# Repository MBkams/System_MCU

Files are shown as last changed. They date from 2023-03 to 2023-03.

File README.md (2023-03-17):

# System_MCU

## Travaux pratiques : Systèmes à microcontroleurs

### 1.2 Le microcontrôleur sous KiCAD

13) Pourquoi PB9 est relié à la maase?
14) Quel est le rôle de L1, C5 et C7 ? :
    Le rôle des composants L1, C5 et C7 est de filtrer la tension d'alimentation venant du 3,3V. L'association de ces composants forme un filtre passe-bas du second ordre.

### 3. Le reste du schéma

3) Quelle page de la datasheet indique les valeurs des condensateurs ? :
   La page 1 : elle indique que la capacité doit être au moins de 0,47uF.
   La page 3 : elle indique que la capacité à une valeur typique de 1uF.
4) Quelle page de la datasheet nous indique les valeurs de condensateurs ? :
   la valeur de condensateurs des  du DAC est donnée en page 25 de la datasheet.

6) Quel est le rôle de la broche CS ?
La broche CS correspond au « Chip Enable » . Un état bas sur cette broche permet d’activer la clock et les données.

7) Quel est le rôle de la broche LDAC ?
La croche LDAC est utilisée pour transférer le registre de verrouillage d'entrée vers le registre du DAC. Lorsque cette broche est à létat bas, la sortie VOUT est mis à jour avec le contenu du registre d'entrée. 

8) Pourquoi le signal MISO n’est pas utilisé ?
Le signal MISO a été connecté directement au STM32, comme décrit dans la procédure. Le signal MOSI transmets les données du maître, le STM32, jusqu’à l’esclave et inversement pour le signal MISO (de l’esclave au maître). Comme on souhaite seulement communiquer du maître jusqu’à l’esclave, on a pas besoin d’utiliser le signal MISO.

10) Où trouve-t-on les indications du pinout du connecteur SWD ?
On trouve ces indications dans le manuel d’utilisation.

### 4. Affectation des empreintes

3) Que signifie 0805 ? 0603 ? 1206 ?
Ces informations corresponent aux dimensions des composants. Exemple avec 0805 : le composent mesure 0.08 pouces sur 0.05 pouces. (a noter que 0.1 pouce égal 2,54 mm)

4) Que signifie LQFP ? SOT-223 ? SOIC ?
QFP décrit le package du composent, cela signifie : Quad Flat Package, qui est un circuit intégré monté en surface. Et LQFP signifie : Low-profile Quad Flat Package, voulant dire que le package est plus petit que le PCB.

SOT : Small-Outline Transistor.
C'est une famille de transistor discrets pour des montages en surface.

SOIC : Small Outline Integrated Circuit 
Boîtier de circuit intégré monté en surface qui occupe une surface inférieure d’environ 30 à 50% à celle d’un boîtier double en ligne (DIP) équivalent, avec une épaisseur typique inférieure de 70%. Ils sont généralement disponibles dans les mêmes brochages que leurs homologues DIP IC. La convention pour nommer le package est SOIC ou SO suivi du nombre de broches. Par exemple, un 4011 à 14 broches serait logé dans un boîtier SOIC-14 ou SO-14. (oui ça vient de Wikipédia, mais on a lu !)

### 3.1 Activation des LL drivers

##### 2. Lors de la génération de code avec la bibliothèque LL, on remarque les changements de synthaxe des appels de fonctions.

##### 4. __STATIC_INLINE permet de définir une fonction en ligne et de la rendre statique.

##### 5. La fonction est définit aussi dans un .h . Néamoins, __STATIC_INLINE permet une optimisation au niveau compilateur lors de l'appel de fonction.

### 3.2 LED simple

##### 2. Pour une configuration du timer de la LED à une fréquence 1kHz et une résolution de 8bits, il faut déterminer les valeurs de PSC et ARR comme suivant :

- Période = (PSC + 1) * (ARR + 1) / Fréquence du clock du timer
- L'horloge du timer est à 32 Mhz. Donc PSC = 125 et ARR = 255.

### 3.3 LED avec timer

##### 3. Les valeurs de PSC et ARR sont 125 et 255 respectivement.

##### 6. La routine d'interruption se situe au nivau TIM21_IRQHandler(void).

##### 7. Avec l'utilisation de la bibliothèque LL, il doit manquer la remise à zero du flag.

##### 8. Cela peut entraîner la routine d'interuption en boucle.

##### 9. Il faut faire une remise à zero du flag.

### 3.4 UART, un simple echo

##### 5. J'ai modifié la défintion des fonctions SerialTransmit et SerialReceiveChar afin de les adapter avec HAL :)

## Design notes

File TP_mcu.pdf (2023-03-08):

# TP Systèmes à microcontrôleurs

L’objectif de ce TP en 4 séances est de concevoir, assembler et tester une carte électronique contenant un microcontrôleur STM32. Le TP a été conçu avec la version 6.0.9 de KiCAD, mais devrait être réalisable avec d’autres versions.

Cette carte sera constituée des composants suivants :
— Microcontrôleur STM32L021K4T6,
— DAC MCP4801-E/SN,
— Régulateur linéaire BU33SD5WG-TR,
— 2 LED au format 0603,
— Connecteur de programmation FTSH-107-01-F-DV,
— Plusieurs composants passifs (résistances, condensateurs...) en 0805.

La carte est donc munie d’un ADC (intégré au MCU) et d’un DAC (composant externe sur la carte). Pour démontrer le bon fonctionnement de la carte, vous programmerez un filtre numérique simple.
L’ordre des séances est le suivant :
1. Schéma, association empreintes
2. Routage du circuit
3. Soudure, test...
4. Écriture du firmware

## 0 Utilisation de git

Les outils de gestion de version permettent de travailler facilement à plusieurs sur du code, ou autre. L’outil git est probablement le plus courant. C’est celui que nous allons utiliser.
Sous Linux, l’outil s’utilise simplement en ligne de commande. Sous Windows, il existe des outils. Je suis un Linuxien, débrouillez-vous.
Git est un outil puissant, complet et complexe, mais nous n’aurons besoin de connaître que 5 commandes :
— git clone : Cloner un projet, c’est la première étape pour récupérer son projet, ou n’importe quel projet publique.
— git pull : Récupérer les dernières modifications
— git add <fichier> : Enregistrer des fichiers auprès de git
— git commit -m "Message" : Réaliser un commit, c’est à dire enregistrer les modifications locales. On peut l’utiliser comme un verbe. Ex : "Oups, j’ai oublié de commiter mon code".
— git push : Pousser du code sur le serveur. Le commit se faisant localement, cette commande permet de pousser le commit sur le serveur.

Je vous recommande fortement d’utiliser cet outil pour tout vos TP, que ce soit pour le code ou pour les compte-rendu.

ENSEA | Page 1/23 | TP Linux Embarqué

1. Si ce n’est pas déjà fait, créez un compte (par étudiant) sur le site suivant : https://github.com/
2. Créez un nouveau repository. Laissez-le en public. Vous pouvez ajouter une description et un fichier README.
3. Récupérez l’adresse du projet. Cliquez sur Code, choisissez SSH, puis copiez l’adresse.

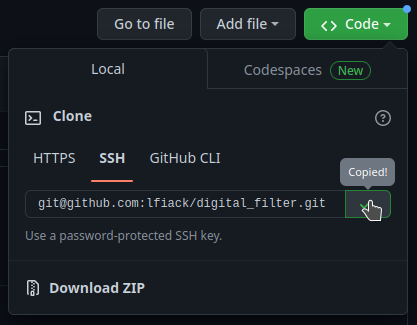
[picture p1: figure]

4. Clonez le projet. Dans un terminal, tapez la commande suivante :
git clone <adresse_du_depot>.
5. Modifiez le fichier README.
6. Réalisez votre premier commit. Tapez les deux commandes suivantes : git add .
git commit -m "First!"
7. Poussez les modifications sur le repository distant :
git push
8. Vérifiez que les modifications ont bien été prises en compte sur https://github.com/

Quelques bonnes pratiques :
— Faire un git pull au début de chaque session de travail (on sait jamais, peut-être que mon binôme a travaillé ?)
— Commiter régulièrement :
— Dès que quelque chose fonctionne
— À la fin de la session de travail
— Éviter de commiter du code qui plante (à l’école, ça peut entrer en contradiction avec le point précédent...)
— Mettez un message utile !
— Utiliser le fichier README comme document de travail.
ENSEA | Page 2/23 | TP Linux Embarqué

## 1 Saisie du schéma

### 1.1 Création de la structure du projet

Le projet contiendra du hardware et du software. Il est impératif de bien structurer le dossier de travail.
1. Dans le dossier git, créez un dossier hardware, un dossier firmware et un dossier datasheets.
2. Téléchargez les datasheets de tous les composants, et copiez les dans le dossier datasheets. Attention, la documentation du STM32 est en plusieurs parties. Téléchargez également la datasheet de la sonde de programmation STLINK-V3MINI. Pensez à commiter.
3. Lancez STM32CubeMX. C’est un outil pratique lors de la conception d’une carte, notamment pour gérer le pinout.
4. Créez un projet pour le STM32L021K4.
5. Dans SYS, activez Debug Serial Wire.
6. Activez l’USART2 en mode Asynchrone. Gardez les paramètres par défaut, et notez le baud rate.
7. Dans l’onglet Clock Configuration, configurez l’horloge système à sa valeur maximale.
8. Dans Project Manager > Code Generator, cochez Generate peripheral initialization as a pair of ’.c/.h’ files per peripheral
9. Sauvegardez dans le dossier firmware. L’initialisation n’est pas terminée, vous y reviendrez en temps voulu.
10. Pensez à commiter.

### 1.2 Le microcontrôleur sous KiCAD

1. Lancez KiCAD. Créez un projet dans le dossier hardware.
2. Cliquez sur Place > Add symbol (Vous pouvez commencer à apprendre les raccourcis.)
3. Chechez et placez le composant STM32L021K4Tx.
4. Cliquez sur Place > Add Power (Aussi présent dans le menu à droite.)
5. Placer GND proche des pins VSS du STM32, et câblez-les comme dans la capture ci-dessous.

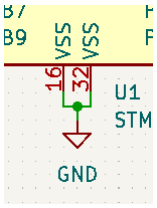
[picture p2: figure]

ENSEA | Page 3/23 | TP Linux Embarqué

6. Ajouter deux autres symboles +3.3V et +3.3VA selon la capture ci-dessous.

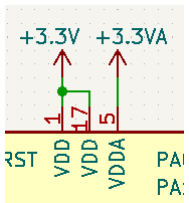
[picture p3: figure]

7. Cliquez sur Place > Add Label Placez le label sur l’entrée NRST et nommez le NRST.

Il sera plus tard relié au port de programmation. Deux signaux connectés à un même label sont reliés électriquement. Ça permet de simplifier la lecture du schéma.
8. Ajoutez les labels correspondant aux signaux définis dans STM32CubeMX (USART2_RX, USART2_TX, SWDIO, SWDCLK).

D’ailleurs, c’est peut-être le bon moment de finaliser le pinout
9. Activez l’entrée IN1 de l’ADC. Ce sera l’entrée analogique pour le filtre.
10. Dans TIM2, mettez Clock Source à Internal Clock et Channel 1 à PWM Generation CH1. On s’en servira pour faire varier la luminosité de la LED.
11. Enfin, configurez les signaux nécessaires pour l’utilisation du DAC. Le résultat final pourrait ressembler à ça :

Sauvegardez.

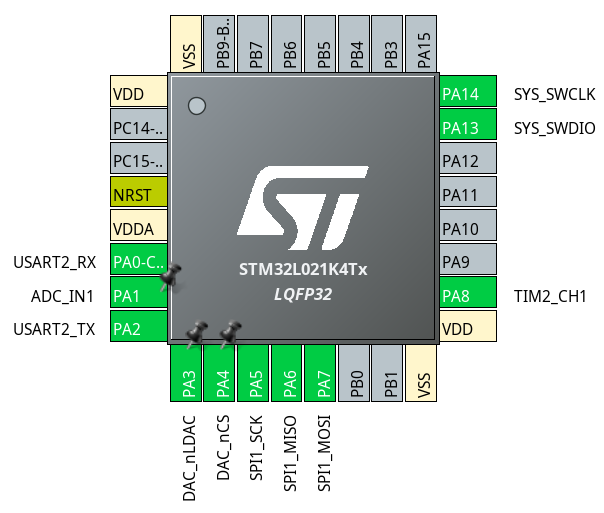
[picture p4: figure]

ENSEA | Page 4/23 | TP Linux Embarqué

12. Il est temps d’ajouter le reste des composants. Ajoutez les composants suivants :
— 6x C_Small
— 1x L_Small
— 2x R_Small
— 1x LED_Small

Le schéma correspondant à la partie microprocesseur pourrait ressembler à ça :

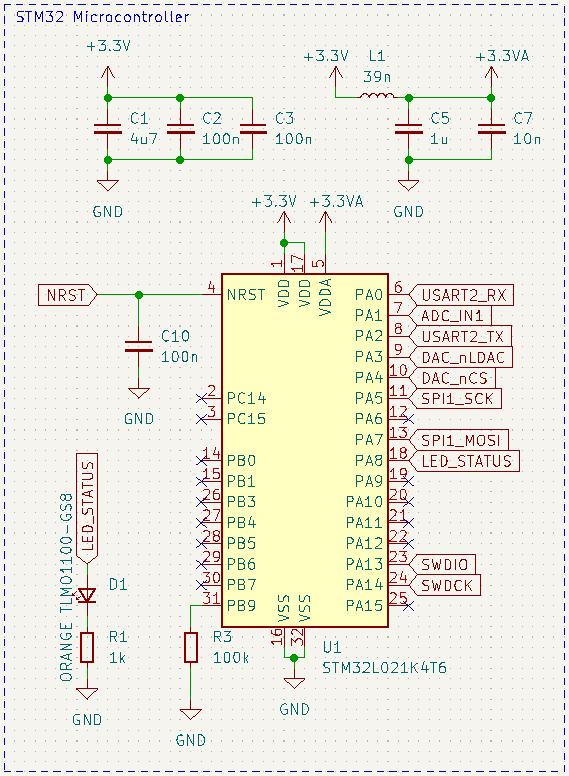
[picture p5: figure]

Notez qu’il n’est pas nécessaire d’annoter les composants à ce stade. Ce sera fait automatiquement plus tard. Les composants peuvent donc être nommés C ?, L ?, U ?...
Par contre, il est important de bien noter les valeurs des composants (4u7, 39n, 1k...)
13. Pourquoi PB9 est relié à la masse ? (Répondez à cette question, et aux suivantes, dans le README du repo git.)
14. Quel est le rôle de L1, C5 et C7 ?
ENSEA | Page 5/23 | TP Linux Embarqué

### 1.3 Le reste du schéma

Pour générer la tension de 3.3V à partir du 5V, nous utiliserons le régulateur linéaire LDO BU33SD5WG-TR. Il n’est pas présent dans la librairie de KiCAD. Pour éviter d’avoir à dessiner un nouveau symbole, nous pouvons simplement utiliser un autre composant qui dispose du même boitier, comme le MCP1802x-xx02xOT.
1. Ajouter le composant MCP1802x-xx02xOT et renommez-le en BU33SD5WG-TR
2. Câblez le régulateur de tension en vous basant sur la figure suivante :

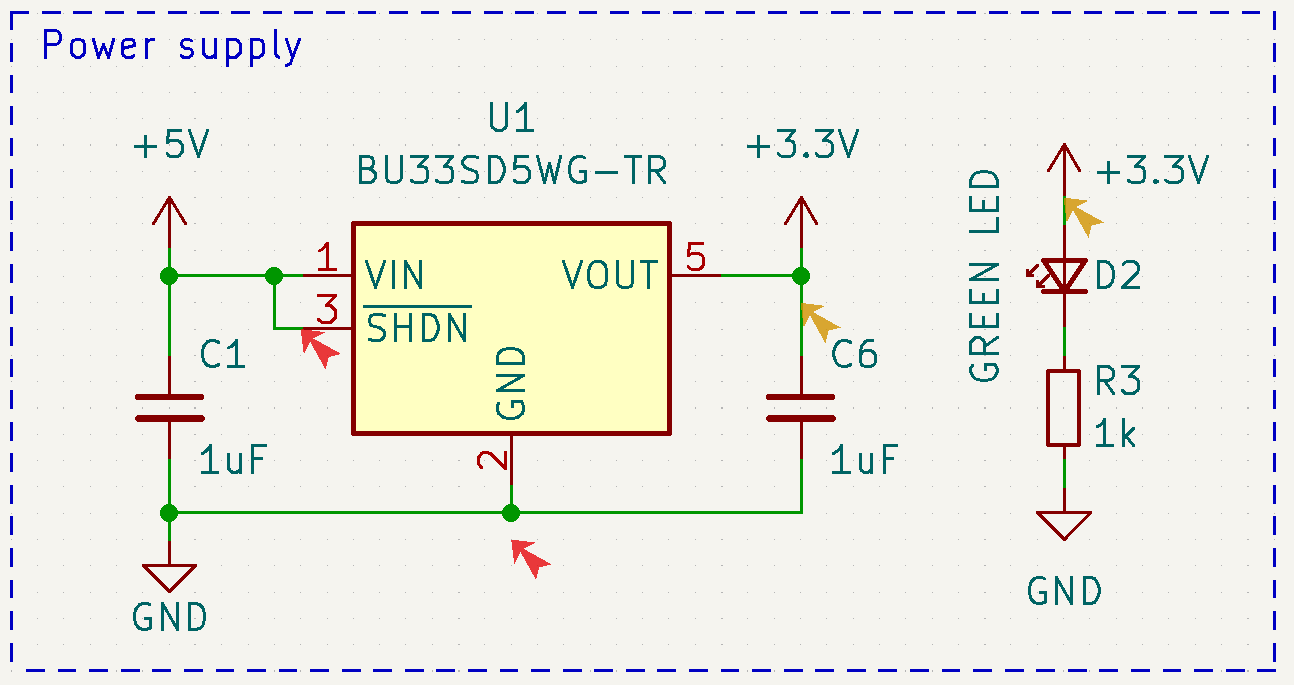
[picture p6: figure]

3. Quelle page de la datasheet indique les valeurs des condensateurs ?
4. Tracez le schéma du DAC en vous inspirant de la figure suivante :

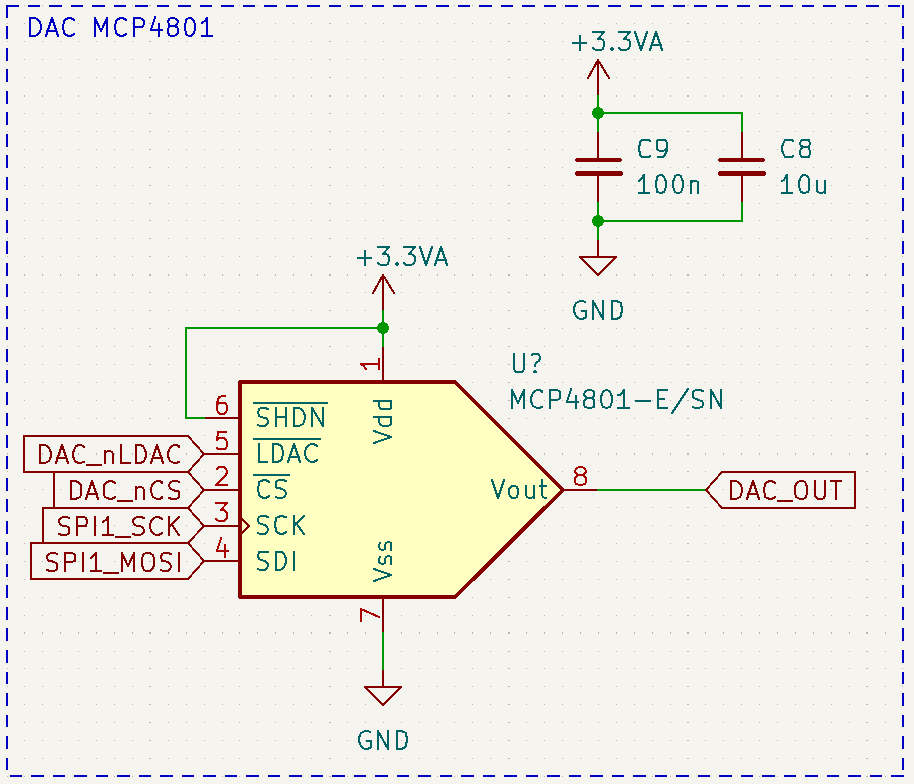
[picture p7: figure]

5. Quelle page de la datasheet nous indique les valeurs de condensateurs ?
6. Quel est le rôle de la broche CS?
7. Quel est le rôle de la broche LDAC ?
8. Pourquoi le signal MISO n’est pas utilisé ?
ENSEA | Page 6/23 | TP Linux Embarqué

9. Câblez les connecteurs comme dans la figure suivante :

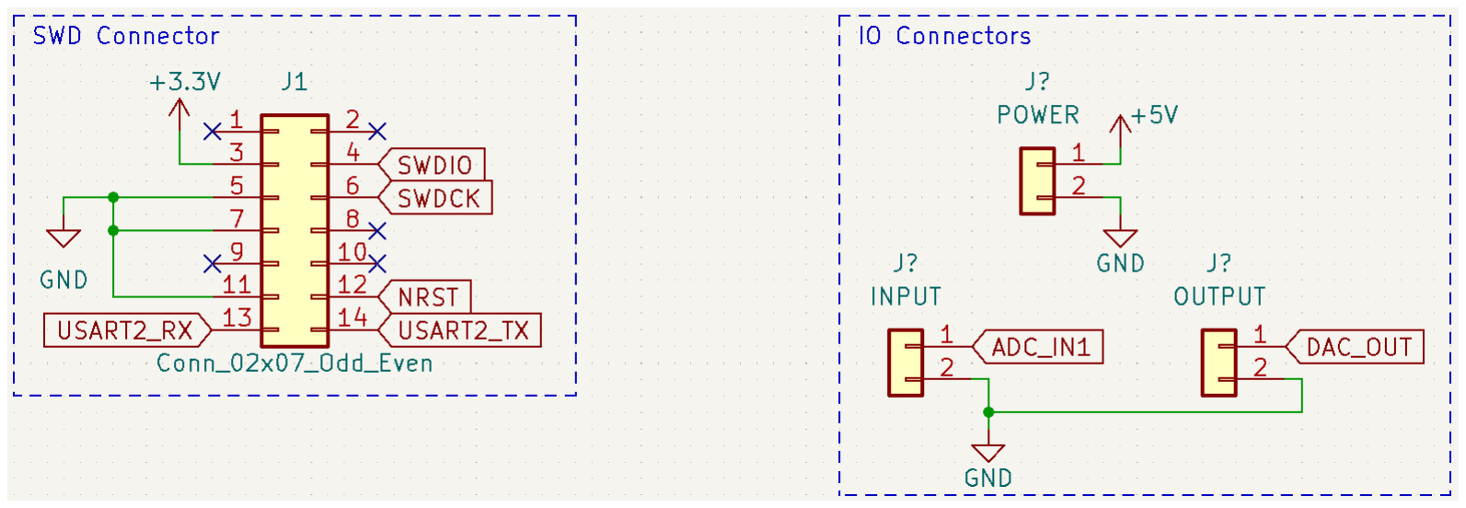
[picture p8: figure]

10. Où trouve-t-on les indications du pinout du connecteur SWD ?
11. Numérotez les composants en cliquant sur Tools > Annotate Schematic...
12. Vérifiez les ERC (Electrical Rule Check) en cliquant sur Inspect > Electrical Rules Checker.
Les erreurs suivantes peuvent être ignorées. S’il y en a plus, c’est qu’il y a peut-être des erreurs dans le schéma, corrigez les.

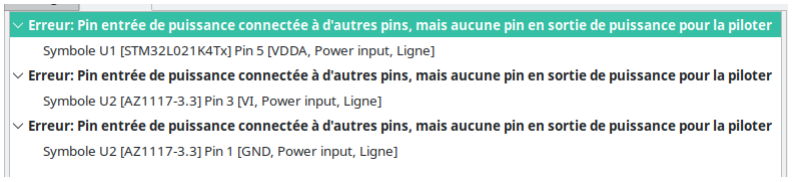
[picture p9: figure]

ENSEA | Page 7/23 | TP Linux Embarqué

### 1.4 Affectation des empreintes

Vous avez fini le tracé du schéma. Il faut maintenant, pour chaque composant, associer un empreinte.
1. Cliquez sur Tools > Assign Footprints...
2. Faire les associations selon la figure suivante. Attention, en fonction du placement des composants dans le schéma, les composants n’ont peut-être pas les mêmes noms.

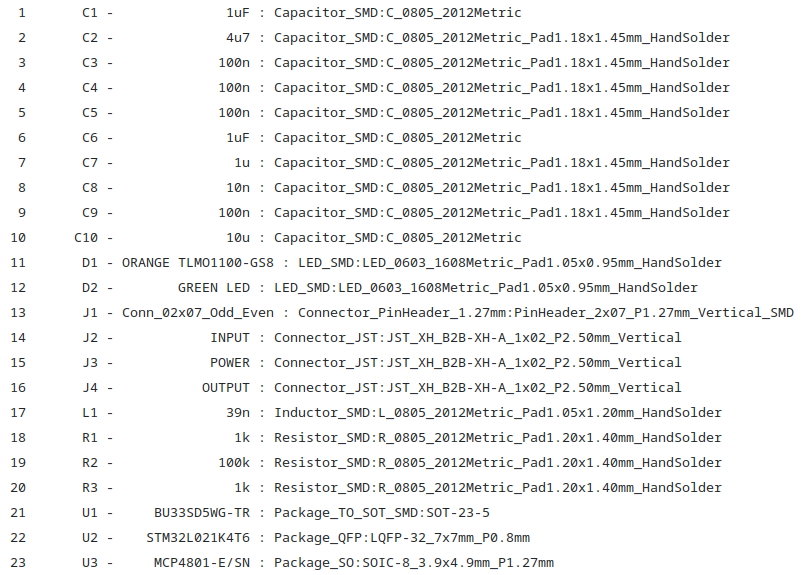
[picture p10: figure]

Pour trouver plus facilement les empreintes, il peut être utile de bien confi-

gurer les filtres
3. Que signifie 0805 ? 0603 ? 1206 ?
4. Que signifie LQFP ? SOT-223 ? SOIC ? Ne vous contentez pas de donner le sigle, j’attends une petite description (vous pouvez copier-coller depuis wikipedia, mais lisez avant quand même))

Félicitations ! Vous avez tracé le schéma complet de votre circuit et avez associé une empreinte à chaque symbole dans le schéma. Dans l’étape suivante, ces informations seront importées dans le logiciel de routage.
Faites vérifier le schéma à l’enseignant avant de passer à la suite.
ENSEA | Page 8/23 | TP Linux Embarqué

## 2 Routage du circuit

### 2.1 Placement des composants

1. Ouvrez l’Éditeur de PCB.
2. Cliquez sur Tools > Update PCB from Schematic...
Les composants sont mis en vrac, les connexions à router sont représentées par des traits fins. Cet ensemble de traits est appelé chevelu (ou ratsnest en Anglais).

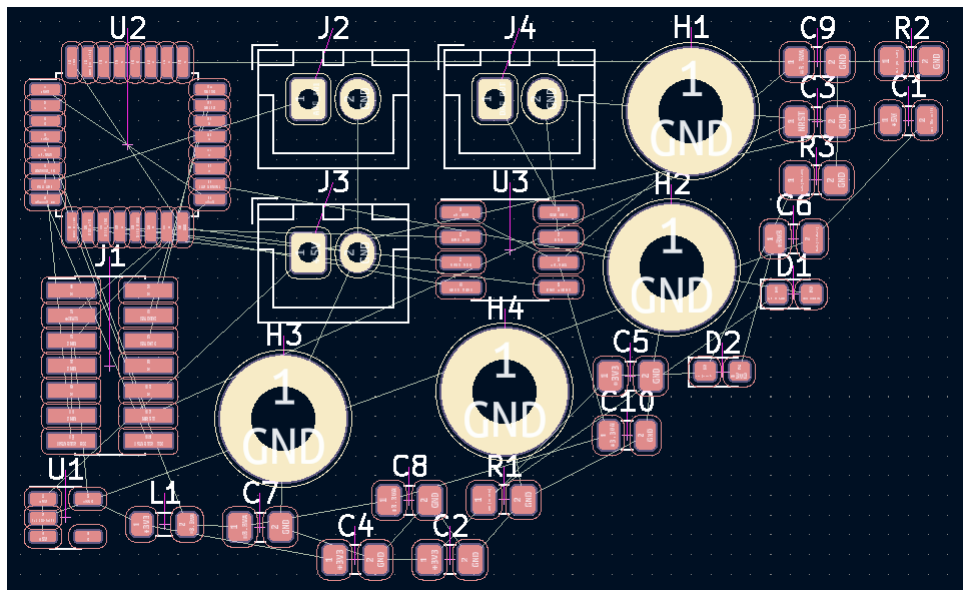
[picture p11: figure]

Dans la figure ci-dessus, il y a 4 grandes pastilles que vous n’avez pas chez vous. Elles serviront de trous de fixation. Il y a plusieurs méthodes pour les ajouter. Vous allez les rajouter dans le schéma.
3. Dans l’Éditeur de Schématique, ajouter les composants suivants :

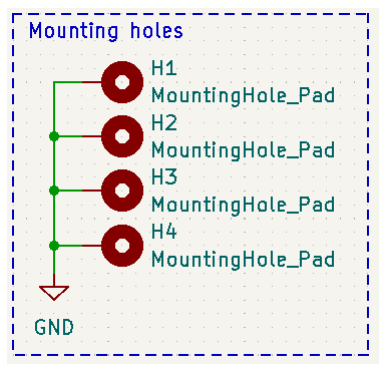
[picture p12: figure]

4. N’oubliez pas de faire le lien avec les empreintes :
5. Réglez la grille à 1mm.
ENSEA | Page 9/23 | TP Linux Embarqué

6. Commencez par placer les trous de fixation à 50mm de distance sur l’axe X et à 40mm de distance sur l’axe Y.
7. Tracez les contours du circuit. Cliquez sur Edge.Cuts dans le panneau de droite. Utilisez les lignes droites et les arcs de cercle pour obtenir quelque chose comme dans la figure suivante :

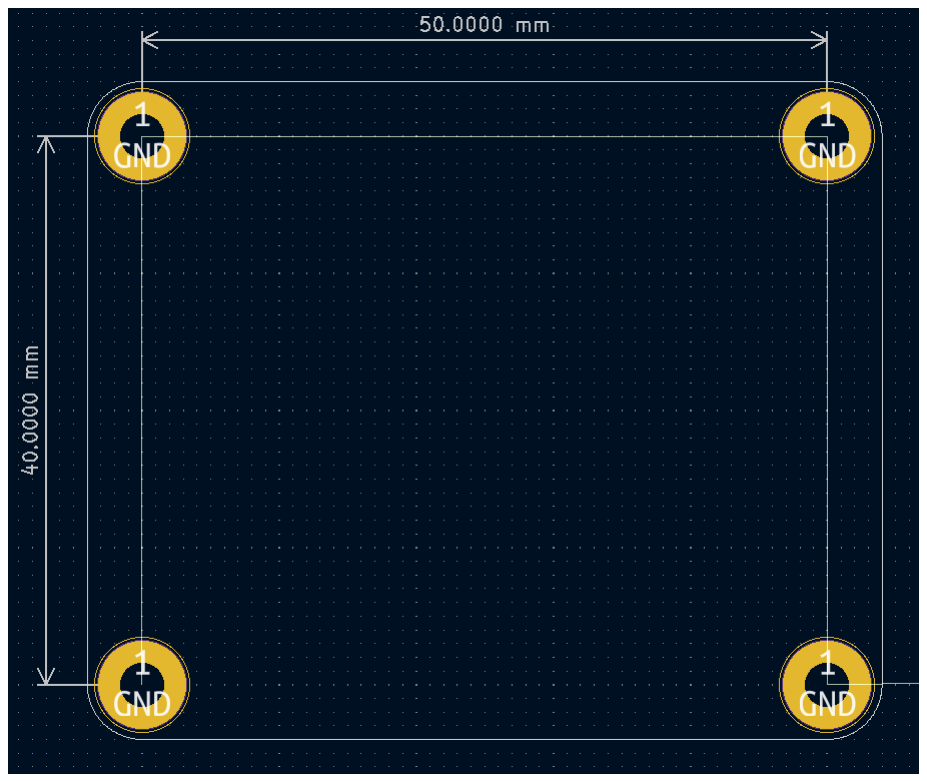
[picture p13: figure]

8. Placez ensuite le connecteur d’alimentation au milieu en haut du circuit, à 4mm du bord. Placez le connecteur pour l’entrée analogique à gauche et le connecteur pour la sortie à droite. Voir la figure suivante :

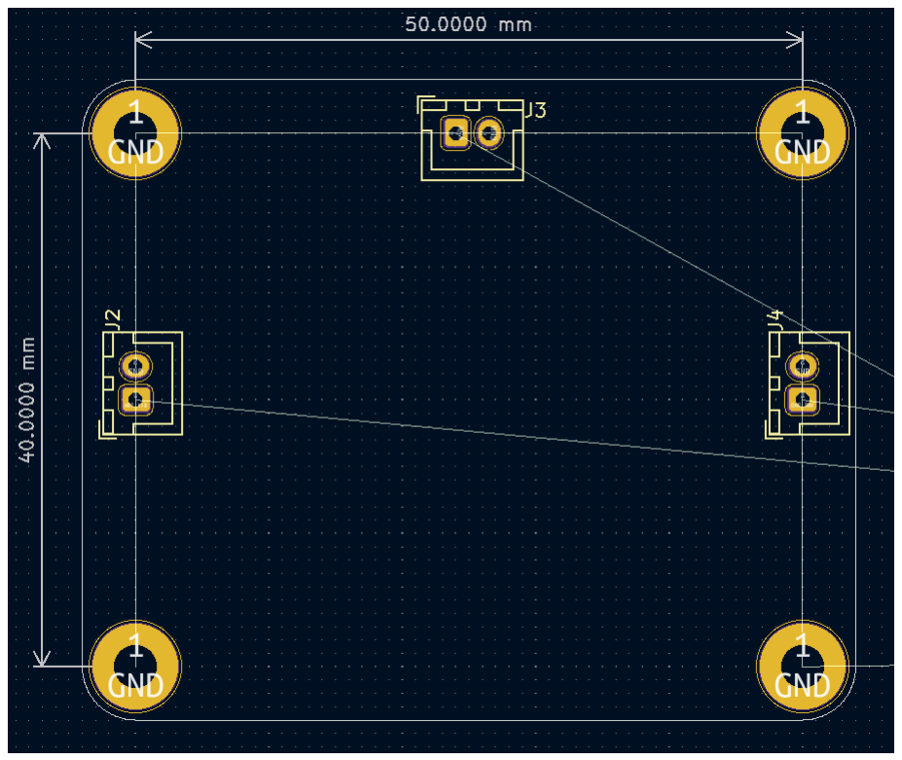
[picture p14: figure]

ENSEA | Page 10/23 | TP Linux Embarqué

9. Cliquez sur Placer > Origine des Coord de Perçage/Placement. Positionnez l’origine sur l’un des trous de fixation. Cette étape est nécessaire pour la fabrication.
10. Pour améliorer la lisibilité, vous pouvez masquer les couches F.Fab et B.Fab
11. Placez les composants. Pour faciliter le routage, il y a quelques règles à respecter.
— Placer le composant le plus complexe (le STM32) au centre.
— Placer les condensateurs de découplage proche des broches d’alimentation à découpler.
— Avoir le schéma ouvert dans une autre fenêtre, sur un autre écran de préférence.
— Essayer de réduire au maximum les croisements dans le chevelu.
— Prendre son temps. Ne pas hésiter à retourner à cette étape si le routage est compliqué.
Une fois les composants placés, faites vérifier par l’enseignant avant de passer à la suite.

### 2.2 Routage

Avant de commencer à router, il faut configurer les règles de routage pour s’assurer que le circuit soit fabricable.
1. Cliquez sur File > Board Setup...
2. Dans Design Rules > Constraints, configurez selon la figure suivante :

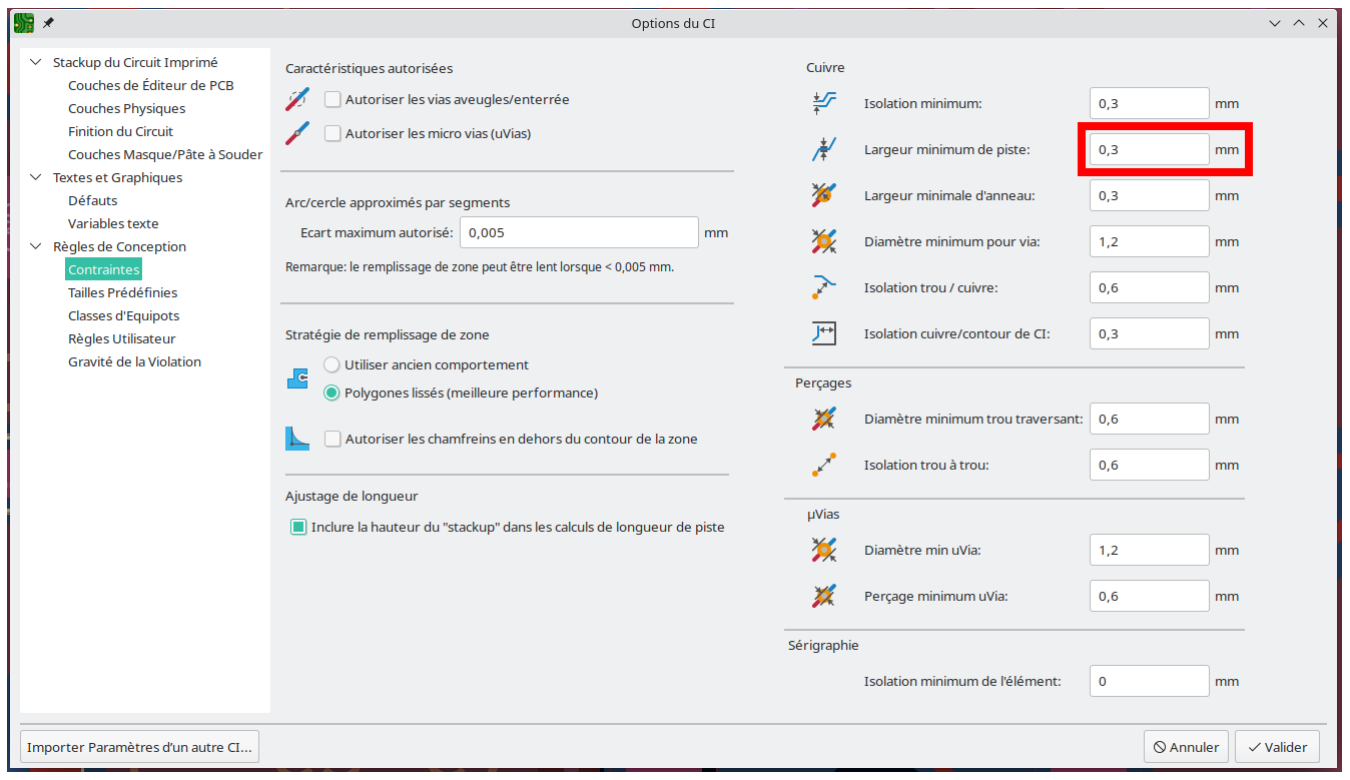
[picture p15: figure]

ENSEA | Page 11/23 | TP Linux Embarqué

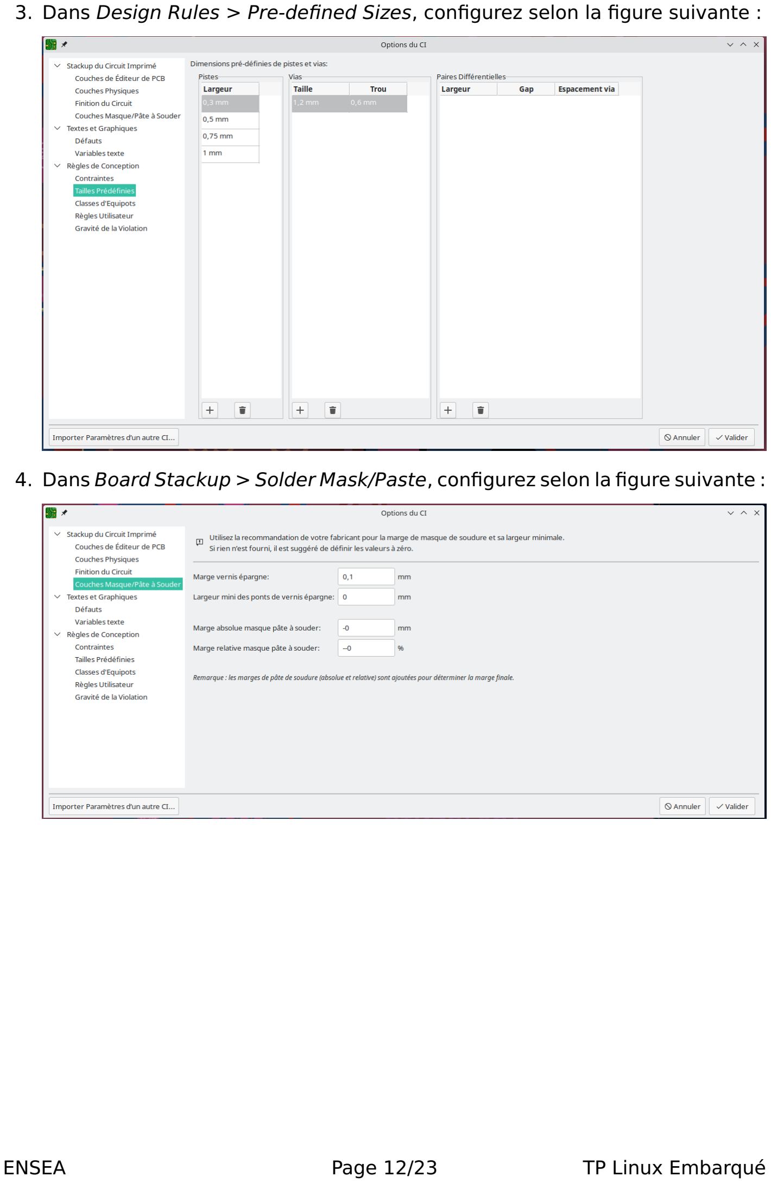
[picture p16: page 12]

3. Dans Design Rules > Pre-defined Sizes, configurez selon la figure suivante :
4. Dans Board Stackup > Solder Mask/Paste, configurez selon la figure suivante :
ENSEA | Page 12/23 | TP Linux Embarqué

5. Dans le panneau de droite, cliquez sur F.Cu. Ensuite, cliquez sur Place > Add Filled Zone.... Choisissez le signal GND. Tracer un rectangle englobant tout le circuit.

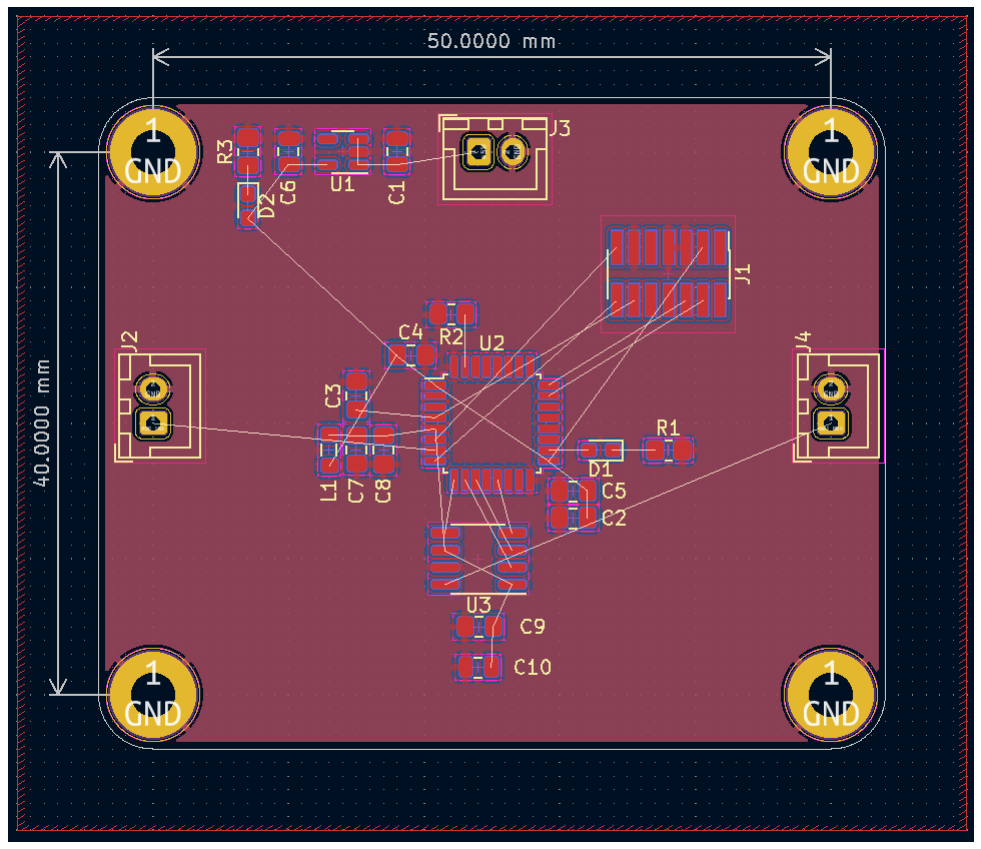
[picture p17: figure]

6. Faites de même avec la couche B.Cu.
7. Pour pouvoir router, cliquez sur View > Drawing Mode > Draw Zone Outlines. (Aussi présent dans le menu de gauche.)
8. Routez la carte. Les pistes de 0.3mm sont reservées aux signaux. Les pistes de 0.5mm, 0.75mm et 1mm sont à utiliser pour les alimentations. C’est encore une étape assez longue. N’hésitez pas à supprimer des pistes déjà routées pour trouver de meilleures solutions. Pensez également à replacer certains composants pour faciliter le routage.

Félicitations vous avez routé la carte ! Faites valider le routage par l’enseignant.

ENSEA | Page 13/23 | TP Linux Embarqué

### 2.3 Génération des fichiers de fabrication

1. Cliquez sur File > Fabrication Outputs > Gerbers (.gbr).
2. Configurer selon la figure suivante :

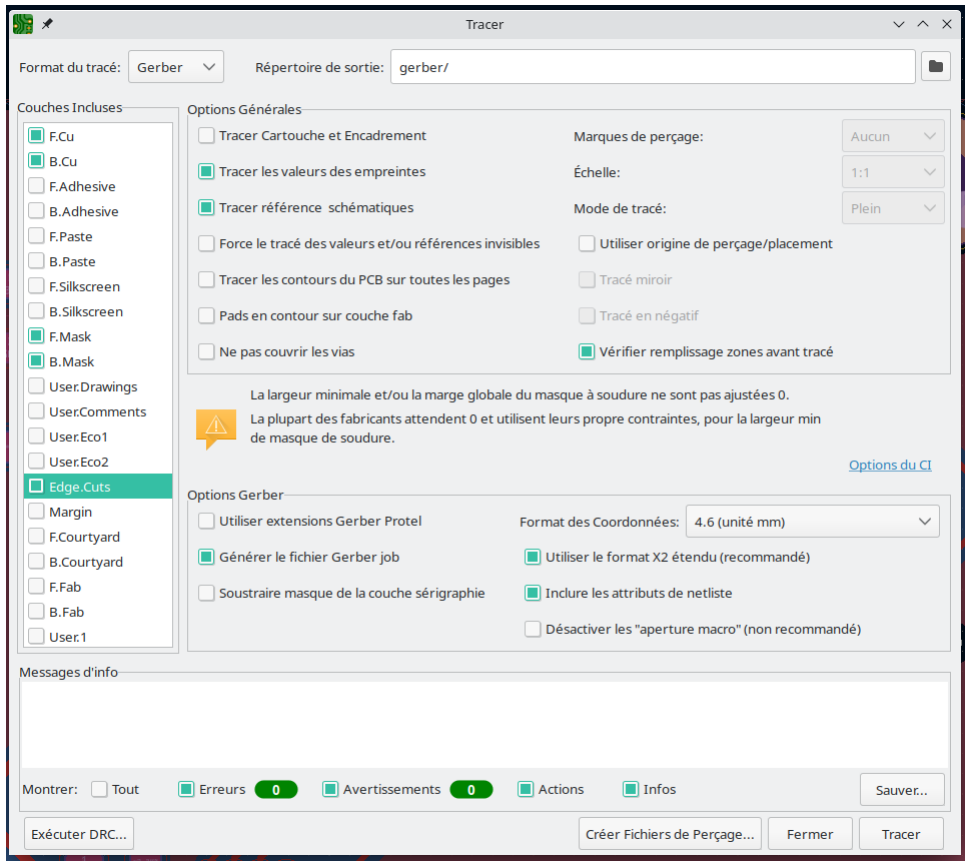
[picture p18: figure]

3. Cliquez sur Créer Fichiers de Perçage...
ENSEA | Page 14/23 | TP Linux Embarqué

4. Configurer selon la figure suivante :

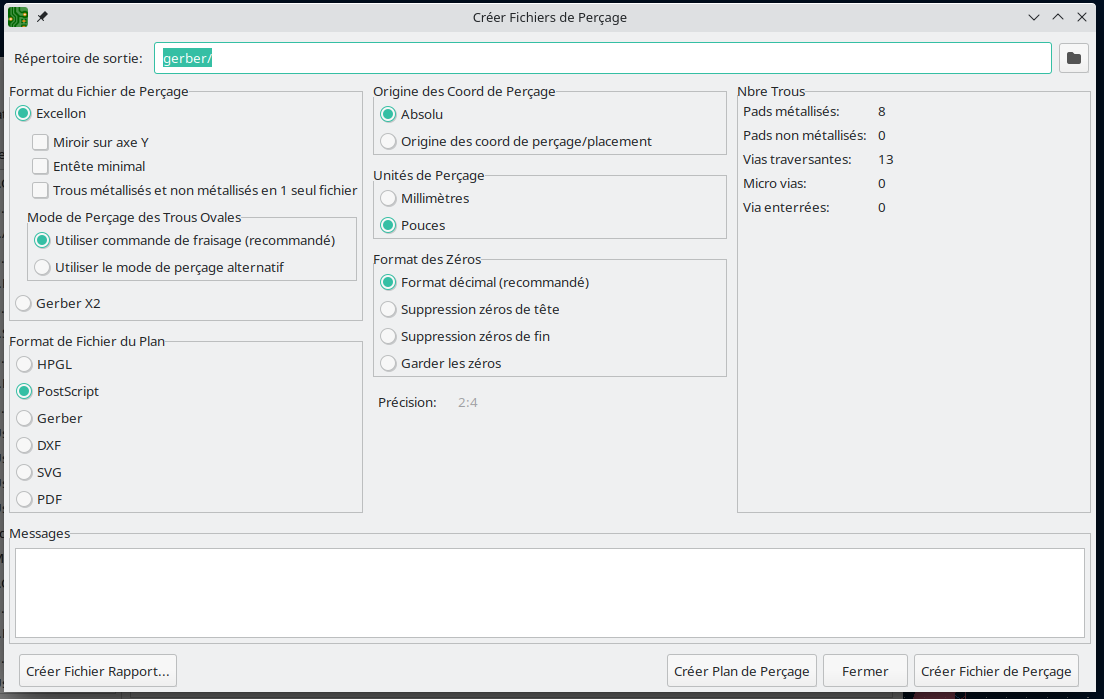
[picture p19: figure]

5. Cliquez sur Créer fichier de perçage
6. Cliquez sur Tracer
7. Faites valider. N’oubliez pas de commiter et de pousser sur github.
ENSEA | Page 15/23 | TP Linux Embarqué

## 3 Écriture du firmware

La section Écriture du firmware est présente avant la section Assemblage parce que, arrivés à cette partie du projet, vous n’avez probablement pas encore votre carte. C’est quelque chose d’assez courant dans une phase de développement.
Néanmoins, il est quand même possible d’avancer :
— On peut tester que le projet compile sur la cible.
— On peut valider l’application sur PC ou sur une autre cible (F746 discovery par exemple).
— On peut tester les drivers sur une autre cible (F746 ou Nucleo).

Vous constaterez rapidement que le STM32L021K4 est assez contraint en mémoire RAM et FLASH. Ainsi, vous allez souvent chatouiller les limites du microcontrôleur.
Ce point vous imposera quelques contraintes :
— Il est hors de question d’utiliser FreeRTOS.
— On ne pourra pas utiliser de nombres flottants.
— On ne pourra pas écrire de structure de drivers trop complexe (on essaiera quand même d’écrire du code propre).
— On ne pourra pas utiliser les fonctions de haut niveau de la HAL.
— On pourra quand même utiliser les Low Layer (LL) drivers.
— On devrait pouvoir utiliser le shell.
ENSEA | Page 16/23 | TP Linux Embarqué

### 3.1 Activation des LL drivers

1. Dans le fichier .ioc, dans Project Manager > Advanced Settings, choisissez LL pour tous les périphériques.

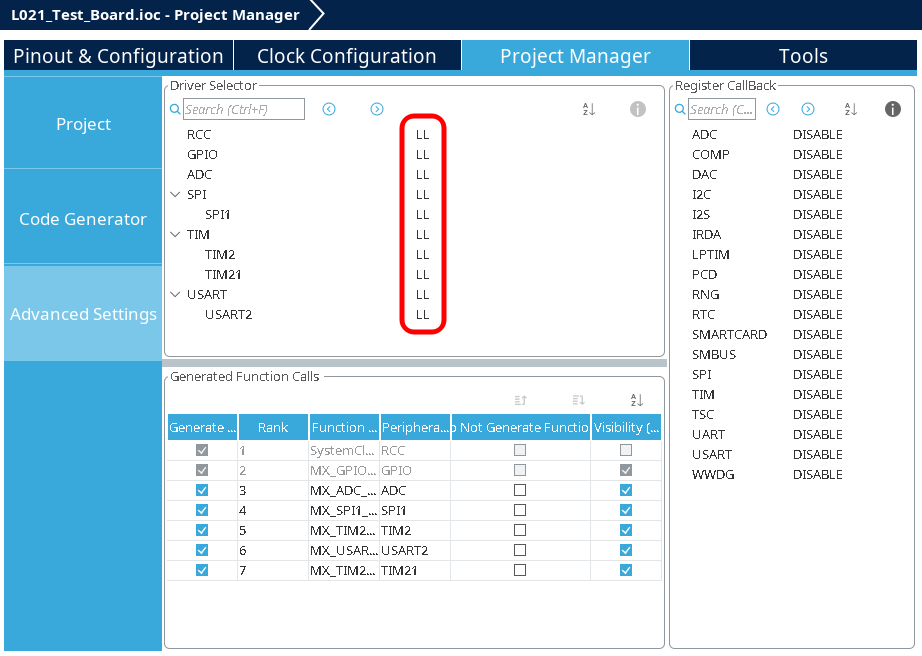
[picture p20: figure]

2. Regardez les fichiers générés. Quelles sont les différences ?
3. Les fonctions de la LL sont des accès directs aux registres. Il faudra chercher de la documentation. Vous aurez besoin du Reference Manual du STM32L021K4 et de la documentation de la HAL STM32L0 (ou lire le code à l’aide de la touche F3 sur CubeIDE).
4. Que signifie __STATIC_INLINE ?
5. Et pourquoi y a-t-il du code dans un .h alors que Môssieur Fiack vous a expressément demandé de pas le faire ? (Les deux questions sont peut-être liés, va savoir)
ENSEA | Page 17/23 | TP Linux Embarqué

### 3.2 LED simple

1. Configurer le timer de la LED pour obtenir une fréquence de découpage d’1kHz et une résolution de 8bits. Ça veut dire que Counter period vaut 255.
2. Quelle valeur donner au prescaler ?
3. Créez une paire de fichiers Led.c / Led.h dans Core/Src et Core/Inc respectivement
4. Écrivez les trois fonctions suivantes :

// Démarre le timer
void LedStart(void);
// Configure le rapport cyclique de la PWM entre 0 et 255
void LedSetValue(uint8_t val);
// À chaque appel, cette fonction incrémente la luminosité de la LED // Arrivé à la valeur maximale, chaque appel décrémente la LED void LedPulse(void);
5. La fonction LEDPulse demande de conserver la luminosité entre deux appels, ainsi qu’une variable permettant de savoir si on incrémente ou décrémente.
6. Si vous n’avez pas peur, vous pouvez stocker ses informations, ainsi que celles relative aux timer, dans une structure. Si c’est pas clair, n’hésitez pas à demander, votre enseignant est payé pour ça.
7. Pour un premier test, la fonction LEDPulse pourra être appelée dans une boucle infinie, accompagnée d’un délai. Ça pourrait ressembler à ça :

/* USER CODE BEGIN WHILE */
LedStart();
while (1) {
// Dans cet exemple, LedPulse fait appel à LedSetValue LedPulse();
LL_mDelay(1);
/* USER CODE END WHILE */

/* USER CODE BEGIN 3 */
}
/* USER CODE END 3 */
8. Vous ne pouvez pas tester le code, n’hésitez pas à le faire valider par votre enseignant.
ENSEA | Page 18/23 | TP Linux Embarqué

### 3.3 LED avec timer

1. Activer le timer qui n’est pas utilisé par la PWM de la LED.
2. Configurez le pour qu’il déclenche une interruption toutes les milli-secondes.
3. Quelles sont les valeurs de PSC et de ARR ?
4. Créez une paire de fichiers TimeBase.c / TimeBase.h
5. Écrivez une fonction :

void TimeBaseStartIT(void);

6. Où se situe la routine de service d’interruption ?
7. Que manque-t-il par rapport au code généré par la HAL ?
8. En quoi est-ce catastrophique ?
9. Que faire ?
10. Déplacer l’appel à la fonction LedPulse() dans la routine de service du timer.
11. Vous ne pouvez pas tester le code, n’hésitez pas à le faire valider par votre enseignant.

### 3.4 UART, un simple echo

1. La configuration de l’UART est probablement correcte par défaut. Vérifiez quand même, ça ne coûte pas grand chose.
2. Créez une paire de fichiers Serial.c / Serial.h
3. Écrivez les fonctions suivantes :

// Cette fonction pourra être utilisée par le Shell v0.4 uint8_t SerialTransmit(char * pData, uint16_t Size);
// Dans cet exemple, on fait du polling, et c'est pas très grave char SerialReceiveChar(void);
4. Écrivez un test permettant de réaliser un echo. Ça pourrait ressembler à ça :

/* USER CODE BEGIN WHILE */
while (1) {
char ch = SerialReceiveChar(); SerialTransmit(ch, 1);
/* USER CODE END WHILE */

/* USER CODE BEGIN 3 */
}
/* USER CODE END 3 */
5. Une erreur s’est glissée dans le code précédent, saurez-vous la retrouver ?
6. Vous ne pouvez pas tester le code, n’hésitez pas à le faire valider par votre enseignant.
ENSEA | Page 19/23 | TP Linux Embarqué

### 3.5 UART et Shell

1. Ajoutez le Shell que vous avez utilisé en TP de FreeRTOS, ou utilisez la toute dernière version disponible à cette adresse : https://github.com/lfiack/mcuLib/tree/main/Middleware/Shell (https://github.com/lfiack/mcuLib/tree/main/Middleware/Shell)
2. Le code pourrait ressembler à quelque chose comme ça :

[...]
/* USER CODE BEGIN PV */
hShell_t hShell;
/* USER CODE END PV */
[...]
int main(void) {
[...]
/* USER CODE BEGIN 2 */
ShellInit(&hShell, &SerialTransmit); /* USER CODE END 2 */
[...]
/* USER CODE BEGIN WHILE */
while (1) {
char c = SerialReceiveByte(); ShellProcess(&hShell, c);
/* USER CODE END WHILE */

/* USER CODE BEGIN 3 */
}
/* USER CODE END 3 */
}
3. Vous ne pouvez pas tester le code, n’hésitez pas à le faire valider par votre enseignant.

### 3.6 DAC, génération de signaux

1. Configurer le SPI dans le fichier .ioc
2. Créez une paire de fichiers AnalogOut.c / AnalogOut.h
3. Écrivez les fonctions suivantes :

void AnalogOutInit(void);
void AnalogOutConvert(uint16_t value);
void AnalogOutPulse(uint16_t increment);

Comme LedPulse(), à chaque appel, cette fonction incrémente la valeur à envoyer au DAC jusqu’à une valeur maximale. Arrivé à la valeur maximale, chaque appel décrémente cette valeur. Ça devrait générer un signal triangle.
4. Testez avec le timer TimeBase. Augmenter la fréquence d’interruption du timer, par exemple à 32kHz.
5. Vous ne pouvez pas tester le code, n’hésitez pas à le faire valider par votre enseignant.
ENSEA | Page 20/23 | TP Linux Embarqué

### 3.7 ADC, un bypass analogique

1. Vous pouvez garde la configuration par défaut de l’ADC.
2. Créez une paire de fichiers AnalogIn.c / AnalogIn.h
3. Écrivez les fonctions suivantes :

void AnalogInInit(void);
void AnalogInStartConversion(void);
// Cette fonction fait du polling, même si c'est pas bien uint16_t AnalogInGetValue(void);
4. Dans la routine de service d’interruption du timer, lire la valeur analogique, et la renvoyer telle quelle sur le DAC. Ça pourrait ressembler à ça :

void TIM21_IRQHandler(void) {
[...]

AnalogInStartConversion();
uint16_t ADCValue = AnalogInGetValue(); uint16_t DACValue = ADCValue; AnalogOutConvert(DACValue);
}
5. Vous ne pouvez pas tester le code, n’hésitez pas à le faire valider par votre enseignant.
ENSEA | Page 21/23 | TP Linux Embarqué

### 3.8 Filtre RC

1. Quelle est la fréquence d’échantillonnage maximale atteignable par l’ADC ? Par le DAC ?
2. Écrivez l’équation différentielle régissant le filtre RC ci-contre. Mettre l’équation sous la forme suivante :
Vin = X ·

dVout(t)
dt + Y · Vout
3. Écrivez l’équation de récurrence correspondante. On peut remplacer dV (t)

dt par V [n]−V [n−1]
T

. Pour faciliter
le codage, on utilisera plutôt l’expression suivante :

fs · (V [n] − V [n − 1])

Avec fs la fréquence d’échantillonnage.

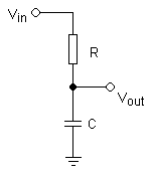
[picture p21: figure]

Mettre sous la forme suivante :

Vout[n] = A · Vin[n] + B · Vout[n − 1]
D
4. Donnez les expressions de A, B et D. Remplacez RC par 1
2·π·fc

5. On travaillera avec une fréquence d’échantillonnage de 32kHz. Combien de cycles processeurs disposons-nous pour traiter chaque échantillon ?
6. Créez une paire de fichiers RCFilter.c / RCFilter.h
7. Créez la structure suivante dans RCFilter.h :

typedef struct {
uint32_t coeffA;
uint32_t coeffB;
uint32_t coeffD;
uint16_t out_prev;
} hRCFilter_t;
8. Écrivez les fonctions suivantes :

// Calcule les coefficients A, B et D
// Et les stocke dans la structure
void RCFilterInit(hRCFilter_t * hRCFilter,
uint16_t cutoffFrequency, uint16_t samplingFrequency); // Implémente l'équation de récurrence
// Faites attention au type des différentes variables
uint16_t RCFilterUpdate(hRCFilter_t * hRCFilter, uint16_t input);
9. Ajoutez une fonction au Shell pour modifier la fréquence de coupure.
10. Vous ne pouvez pas tester le code, n’hésitez pas à le faire valider par votre enseignant.
ENSEA | Page 22/23 | TP Linux Embarqué

## 4 Assemblage

1. Avant de souder, faites un test de continuité. Vérifiez également qu’il n’y ait pas de courts circuits.
2. Soudez les composants :
— Commencez par les circuits intégrés (STM32, DAC, LDO)
— Continuez avec les petits composants (Condensateurs, résistances, LED) — Soudez ensuite le connecteur SWD
— Finissez avec le connecteur 4 pin au bottom de la carte.
3. Alimentez la carte. Régler une limitation de courant de 100mA au niveau de l’alimentation.
4. Mesurer les différentes tensions d’alimentation (VDD et VDDA).
5. Branchez la STLINKV3-Mini et testez la communication, d’abord avec l’outil stlink-gui puis en programmant un firmware simple.
6. Testez ensuite les différents firmwares :
(a) LED simple
(b) LED + timer
(c) UART
(d) UART + Shell
(e) DAC avec timer
(f) Bypass ADC -> DAC. Attention niveaux de tension ! Ne pas descendre en dessous de 0V, ne pas monter au dessus de 3,3V. Vérifier à l’oscilloscope avant d’appliquer le signal.
(g) Filtre RC
ENSEA | Page 23/23 | TP Linux Embarqué

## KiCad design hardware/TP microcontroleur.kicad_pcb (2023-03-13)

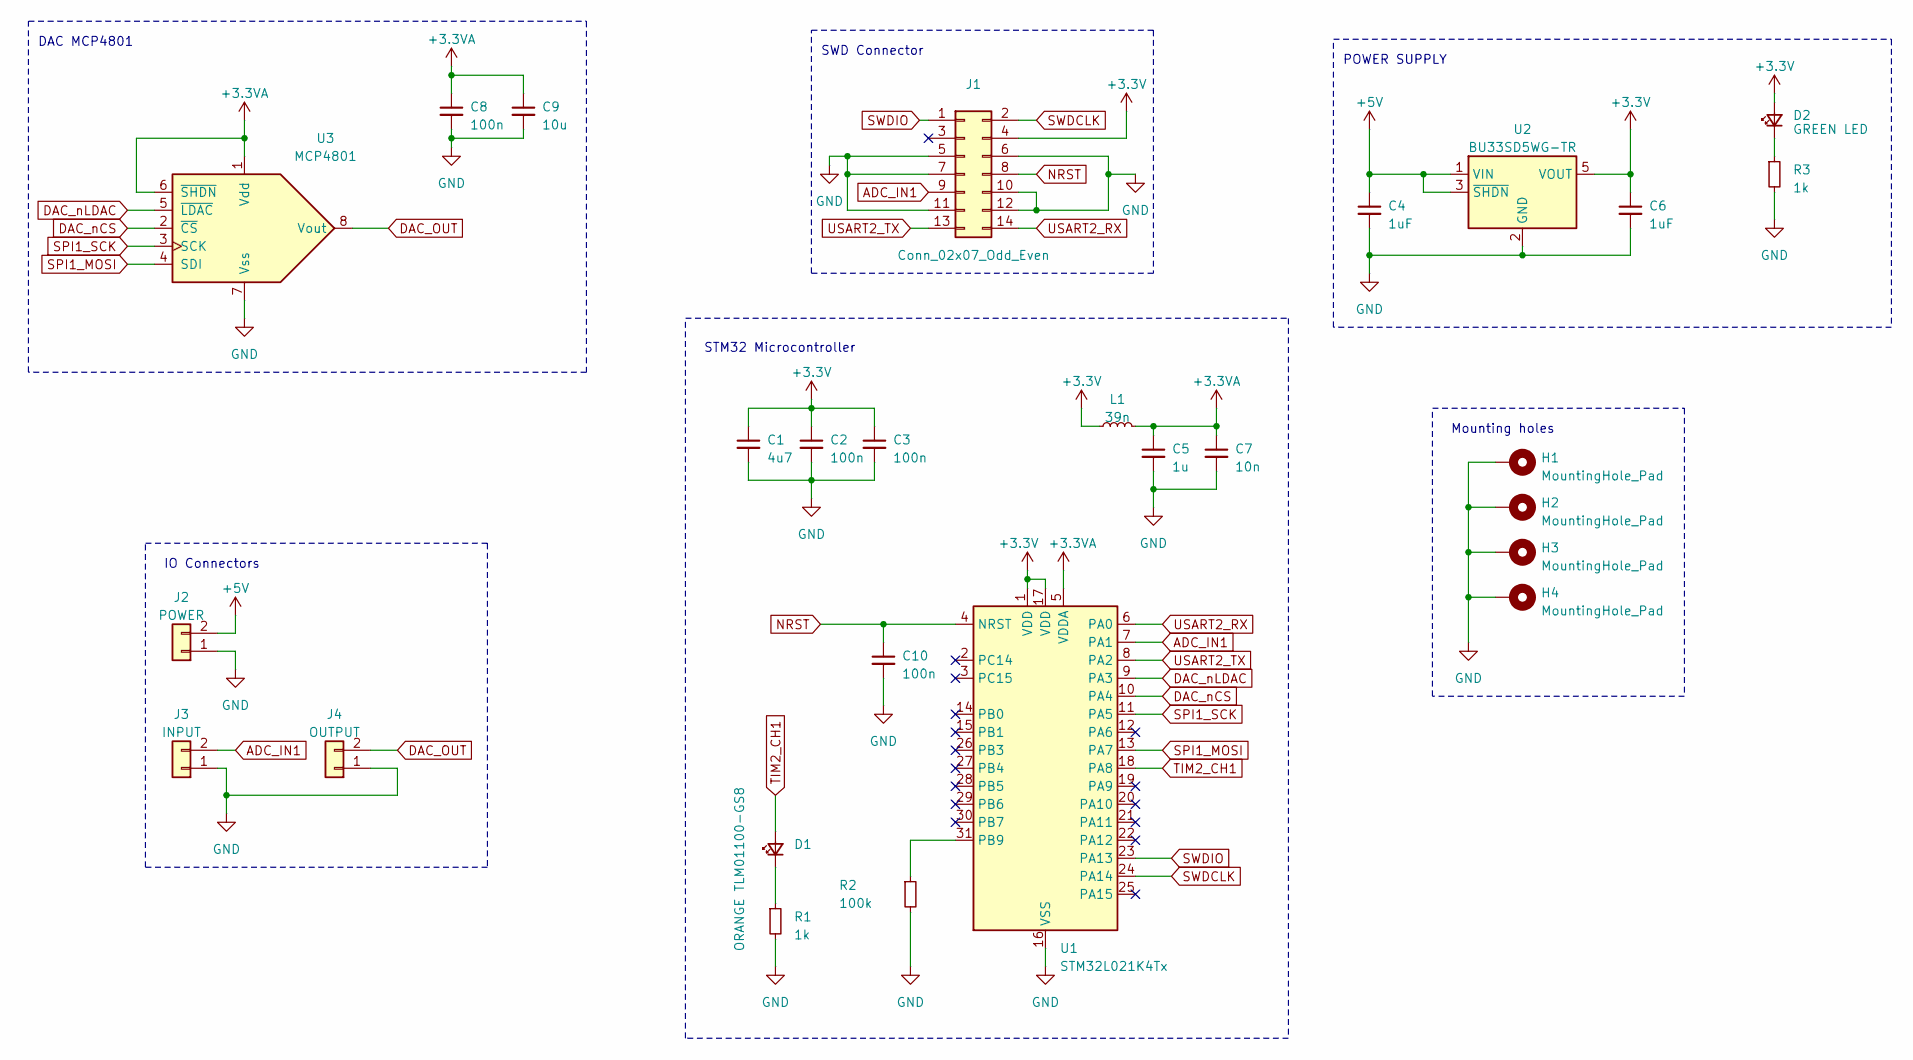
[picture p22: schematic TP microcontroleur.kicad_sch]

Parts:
C1: 4u7; C_0805_2012Metric_Pad1.18x1.45mm_HandSolder
C2, C3, C8, C10: 100n; C_0805_2012Metric_Pad1.18x1.45mm_HandSolder
C4, C6: 1uF; C_0805_2012Metric
C5: 1u; C_0805_2012Metric_Pad1.18x1.45mm_HandSolder
C7: 10n; C_0805_2012Metric_Pad1.18x1.45mm_HandSolder
C9: 10u; C_0805_2012Metric
D1: ORANGE TLM01100-GS8; LED_0603_1608Metric_Pad1.05x0.95mm_HandSolder
D2: GREEN LED; LED_0603_1608Metric_Pad1.05x0.95mm_HandSolder
H1, H2, H3, H4: MountingHole_Pad; MountingHole_3.2mm_M3_Pad
J1: Conn_02x07_Odd_Even; PinHeader_2x07_P1.27mm_Vertical_SMD
J2: POWER; JST_XH_B2B-XH-A_1x02_P2.50mm_Vertical
J3: INPUT; JST_XH_B2B-XH-A_1x02_P2.50mm_Vertical
J4: OUTPUT; JST_XH_B2B-XH-A_1x02_P2.50mm_Vertical
L1: 39n; L_0805_2012Metric_Pad1.05x1.20mm_HandSolder
R1, R3: 1k; R_0805_2012Metric_Pad1.20x1.40mm_HandSolder
R2: 100k; R_0805_2012Metric_Pad1.20x1.40mm_HandSolder
U1: STM32L021K4Tx; LQFP-32_7x7mm_P0.8mm
U2: BU33SD5WG-TR; SOT-23-5
U3: MCP4801; SOIC-8_3.9x4.9mm_P1.27mm

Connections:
+3.3V: C1.1, C2.1, C3.1, C6.1, D2.2 (A), J1.4, L1.1, U1.1 (VDD), U1.17 (VDD), U2.5 (VOUT)
+3.3VA: C5.1, C7.1, C8.1, C9.1, L1.2, U1.5 (VDDA), U3.1 (Vdd), U3.6 (~SHDN)
+5V: C4.1, J2.2, U2.1 (VIN), U2.3 (~SHDN)
ADC_IN1: J1.9, J3.2, U1.7 (PA1)
DAC_OUT: J4.2, U3.8 (Vout)
DAC_nCS: U1.10 (PA4), U3.2 (~CS)
DAC_nLDAC: U1.9 (PA3), U3.5 (~LDAC)
GND: C1.2, C2.2, C3.2, C4.2, C5.2, C6.2, C7.2, C8.2, C9.2, C10.2, H1.1, H2.1, H3.1, H4.1, J1.5, J1.6, J1.7, J1.10, J1.11, J1.12, J2.1, J3.1, J4.1, R1.2, R2.2, R3.2, U1.16 (VSS), U1.32 (VSS), U2.2 (GND), U3.7 (Vss)
NRST: C10.1, J1.8, U1.4 (NRST)
unnamed: D1.1 (K), R1.1
unnamed: D2.1 (K), R3.1
unnamed: R2.1, U1.31 (PB9)
SPI1_MOSI: U1.13 (PA7), U3.4 (SDI)
SPI1_SCK: U1.11 (PA5), U3.3 (SCK)
SWDCLK: J1.2, U1.24 (PA14)
SWDIO: J1.1, U1.23 (PA13)
TIM2_CH1: D1.2 (A), U1.18 (PA8)
USART2_RX: J1.14, U1.6 (PA0)
USART2_TX: J1.13, U1.8 (PA2)

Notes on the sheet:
STM32 Microcontroller
Mounting holes
IO Connectors
DAC MCP4801
POWER SUPPLY
SWD Connector

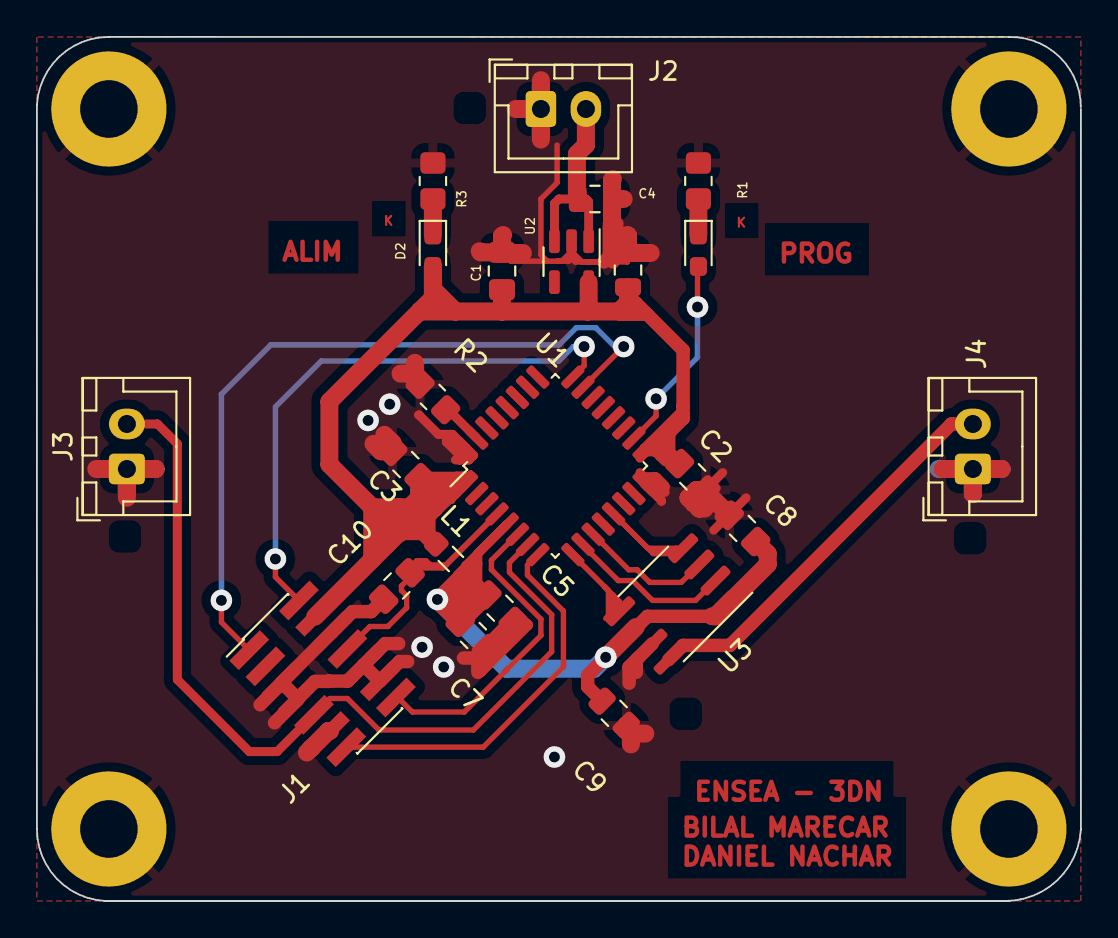
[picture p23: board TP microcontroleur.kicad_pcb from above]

Board: 2 copper layers, 58.0 x 48.0 mm, 27 parts (0 on the bottom side), 19 nets.

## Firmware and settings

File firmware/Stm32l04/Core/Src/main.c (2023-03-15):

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
/* Includes ------------------------------------------------------------------*/
#include "main.h"
#include "adc.h"
#include "spi.h"
#include "tim.h"
#include "usart.h"
#include "gpio.h"
#include "Serial.h"


void SystemClock_Config(void);
/**
  * @brief  The application entry point.
  * @retval int
  */
int main(void)
{
  /* MCU Configuration--------------------------------------------------------*/

  /* Reset of all peripherals, Initializes the Flash interface and the Systick. */
  HAL_Init();

  /* Configure the system clock */
  SystemClock_Config();

  /* Initialize all configured peripherals */
  MX_GPIO_Init();
  MX_USART2_UART_Init();
  MX_ADC_Init();
  MX_SPI1_Init();
  MX_TIM2_Init();
  MX_TIM21_Init();
  /* USER CODE BEGIN 2 */
  //LedStart();
  //TimeBaseStartIT();
  /* USER CODE END 2 */

  /* Infinite loop */
  /* USER CODE BEGIN WHILE */
  while (1)
  {
    //HAL_GPIO_WritePin( GPIOA, GPIO_PIN_8, GPIO_PIN_SET );
    //HAL_Delay(1000);
    //HAL_GPIO_WritePin( GPIOA, GPIO_PIN_8, GPIO_PIN_RESET );
    //HAL_Delay(1000);
    
    //LedPulse();
    //HAL_Delay(100); 

    char ch;
    SerialReceiveChar(&ch,1);
    SerialTransmit(&ch, 1);

    /* USER CODE END WHILE */

    /* USER CODE BEGIN 3 */
  }
  /* USER CODE END 3 */
}

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


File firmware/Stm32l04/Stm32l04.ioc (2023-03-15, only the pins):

Mcu.UserName=STM32L021K4Tx
PA0-CK_IN.Signal=USART2_RX
PA1.Signal=ADC_IN1
PA13.Signal=SYS_SWDIO
PA14.Signal=SYS_SWCLK
PA2.Signal=USART2_TX
PA3.GPIO_Label=DAC_nLDAC
PA3.Signal=GPIO_Output
PA4.GPIO_Label=DAC_nCS
PA4.Signal=GPIO_Output
PA5.Signal=SPI1_SCK
PA7.Signal=SPI1_MOSI
PA8.Signal=S_TIM2_CH1

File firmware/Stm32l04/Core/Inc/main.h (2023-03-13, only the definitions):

#define DAC_nLDAC_Pin GPIO_PIN_3
#define DAC_nLDAC_GPIO_Port GPIOA
#define DAC_nCS_Pin GPIO_PIN_4
#define DAC_nCS_GPIO_Port GPIOA

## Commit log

2023-03-08 MCU Board under KiCad
    [Board.kicad_pcb, Board.kicad_sch]
2023-03-08 Board schematic
    [Board.kicad_sch]
2023-03-10 LED Blinker
2023-03-13 Board with PCB
    [TP microcontroleur.kicad_pcb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]
2023-03-14 LED with PWM and HAL library
2023-03-15 Led Simple
2023-03-15 UART, un simple echo

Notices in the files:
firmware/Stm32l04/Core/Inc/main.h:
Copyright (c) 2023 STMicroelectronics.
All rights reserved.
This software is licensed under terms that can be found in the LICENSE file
